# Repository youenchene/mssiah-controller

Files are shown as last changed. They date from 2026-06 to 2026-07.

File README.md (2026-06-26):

# MSSIAH Controller

3D-printable enclosure (case) for a DIY MSSIAH controller for the Commodore 64.
Designed in OpenSCAD — two-piece snap-together case with a 20° sloped face,
parametric dimensions, and integrated heat-set insert pockets.

## What is the MSSIAH controller?

[MSSIAH](https://mssiah.com/mssiah.php) is a cartridge/software suite that turns
the Commodore 64 into a MIDI workstation and synthesizer.

This project reproduces a custom physical controller enclosure inspired by the
build documented at [c64customs](https://c64customs.blogspot.com/2021/08/custom-diy-mssiah-controller.html).
The controller connects to the C64 via the **user port (CB8)** through a DB9
connector, and provides physical knobs, a joystick, and an arcade button to
interact with the MSSIAH software.

## STL models

Pre-built STL files are in the [`stl/`](stl/) directory once exported.

To generate them yourself from the parametric source:

1. Open `main.scad`, `bac.scad`, or `couvercle.scad` in [OpenSCAD](https://openscad.org/)
2. Hit **F6** to render
3. File → Export → Export as STL

| File | Part | Description |
|---|---|---|
| `stl/bac.stl` | Bac (bottom) | Flat base + walls + boss pillars + alignment lip |
| `stl/couvercle.stl` | Couvercle (top) | Sloped face with all control cutouts + DB9 opening |

> The `.scad` source is parametric — adjust dimensions in
> [`lib/dimensions.scad`](lib/dimensions.scad) before exporting to adapt the
> enclosure to different components or tolerances.

## Hardware list

### Electronic components

| Qty | Component | Key specs | Source |
|-----|---|---|---|
| 4× | **Potentiometer** B10K rotary | Shaft Ø 9.7 mm, hex nut 13.85 mm AF, decorative washer Ø 41 mm, knob Ø 26.5 mm | [AliExpress](https://fr.aliexpress.com/item/32847136499.html) |
| 1× | **Joystick** analog (PS2-style) | Cap Ø 15 mm, PCB 34×34 mm, 4 mounting holes Ø 2.5 mm at 35 mm center distance | [AliExpress](https://fr.aliexpress.com/item/1005005367139157.html) |
| 1× | **Arcade button** Sanwa OBSF-30 | Snap-in, head Ø 30 mm, collar Ø 33 mm | [Amazon](https://www.amazon.fr/dp/B01MRWL6DW) |
| 1× | **DB9 connector** female 9-pin | Chassis-mount, body ~30×13 mm, 2 mounting holes | [AliExpress](https://fr.aliexpress.com/item/1005009405056447.html) |

### Fasteners & inserts

| Usage | Insert | Screw | Qty |
|---|---|---|-----|
| Joystick mounting | M2.5 (Ø 3.5 ext, length 4 mm) | M2.5 × 8 mm | 4 |
| DB9 connector | M3 (Ø 5 ext, length 4 mm) | M3 × 8 mm | 2 |
| Case assembly (bac → couvercle) | M3 (Ø 5 ext, length 4 mm) | M3 × 10 mm | 4 |
| Potentiometers | — (hex nut M6 provided) | — | 4 |
| Arcade button | — (snap-in) | — | 1 |
| Feet | — | Adhesive pads Ø 11 mm ([AliExpress](https://fr.aliexpress.com/item/1005006618909639.html)) | 4 |

**Inserts to buy**: 4× M2.5 brass heat-set inserts (Ø 3.5 ext, length 4 mm).
M3 inserts (×6 total) are assumed already in inventory.

### Tools

- Soldering iron (or dedicated insert press) for heat-set inserts
- M2.5 and M3 hex drivers
- OpenSCAD (free, [openscad.org](https://openscad.org/)) to view or modify the model

## Project structure

```
.
├── main.scad          # Full assembly (view: assembled or exploded)
├── bac.scad           # Bottom half — base, walls, bosses, alignment lip
├── couvercle.scad     # Top half — sloped face, control cutouts, DB9 opening
├── lib/
│   ├── dimensions.scad   # All dimensional variables
│   ├── inserts.scad      # Parametric heat-set insert modules
│   ├── composants.scad   # Cutout modules for each component
│   └── passe_cables.scad # Internal cable-routing arches
├── stl/               # Exported STL files
├── PLAN.md            # Full design specification (in French)
├── CONTEXT.md         # Glossary & terminology (in French)
└── LICENSE
```

## Opening in OpenSCAD

Open `main.scad` to see the full assembly. Toggle the flags at the top:

```openscad
EXPLODED = true;        // true = exploded view, false = assembled
SHOW_BAC = true;
SHOW_COUVERCLE = true;
```

Set `EXPLODED = false` for a print-ready view before exporting.

## License

[Unlicense](LICENSE) — public domain. Do whatever you want.

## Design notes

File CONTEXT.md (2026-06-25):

# Glossary — MSSIAH Controller Enclosure

## Parts

- **Bottom** : lower half of the enclosure. Flat base + 4 vertical walls + 4 fixation bosses. Receives the electronics from underneath.
- **Cover** : upper half of the enclosure. Carries the sloped face on which the controls are mounted (joystick, button, potentiometers). Screws onto the bottom.
- **Sloped face** : flat surface at 20° to the horizontal, facing the operator (back high, front low). Carries all controls.
- **Boss** : vertical cylindrical pillar printed inside the bottom, containing a heat-set insert. Serves as a fixation point to screw the cover on.
- **Local reinforcement** : thickened area of the sloped face (or a wall) at a component location, to house an insert or nut and stiffen the fixation.
- **Male lip** : stepped rim on the bottom perimeter, which inserts into the cover groove for self-alignment.
- **Groove** : female channel in the cover rim, which receives the bottom's male lip.
- **Cable guide** : small arch printed in relief on the inner face of the cover, under which cables pass for routing.

## Electronic Components

- **Potentiometer (pot)** : rotary potentiometer B10K. Threaded shaft Ø 9.7 mm, hex nut 13.85 mm across-flats, decorative washer Ø 41 mm, knob Ø 26.5 mm. Body Ø 28 mm, height 12.6 mm under the face.
- **Joystick** : analog module (PS2 type). Cap Ø 15 mm, wider base, PCB 34×34 mm with 4 fixation holes Ø 2.5 mm (M2.5 screws) at 35 mm spacing. Mounted under the sloped face, cap protrudes through Ø 32 mm hole. Fixation via M2.5 heat-set inserts (Ø 3.5 ext, length 4 mm) + M2.5 screws.
- **Arcade button** : Sanwa OBSF-30, snap-in. Head Ø 30 mm, collar Ø 33 mm, depth ~40 mm under the face. Clips into a Ø 30 mm hole, no screws.
- **DB9** : female 9-pin chassis connector. Body ~30×13 mm, fixed by 2 M3 screws on the back face. Connects the controller to the C64's CB8 port.

## Heat-Set Inserts

- Knurled brass inserts, heated and pressed into plastic. Metric internal threading.
- Available inventory : M2 (length 2 and 4), M2.5 (length 4, to purchase), M3 (4/6/8), M4 (4/6/8), M5 (4/6/8), M6, M8 (6/10).
- External diameters : M2=3.2, M3=5, M4=6, M5=7, M6=8, M8=10 mm.

## Fasteners Used in This Project

| Use | Insert | Screw | Plastic Drilling |
|---|---|---|---|
| Joystick (×4) | M2.5, Ø 3.5 ext, length 4 mm | M2.5 × 8 mm | Ø 3.0 mm, depth 5 mm |
| DB9 (×2) | M3, Ø 5 ext, length 4 mm | M3 × 8 mm | Ø 4.0 mm, depth 5 mm |
| Bottom/cover assembly (×4) | M3, Ø 5 ext, length 4 mm | M3 × 10 mm | Ø 4.0 mm, depth 5 mm |
| Potentiometers (×4) | None (M6 embedded hex nut supplied) | M6 nut supplied | 14 mm hex socket |

## Sloped Face Coordinate System

- Origin : bottom-left corner (front-left as seen by operator).
- X axis : width (0 to 120 mm), left → right.
- Y axis : length along the slope (0 to ~170 mm), front → back.
- "Up" of the joystick = toward the back of the enclosure (top of the slope).

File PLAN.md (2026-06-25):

# Plan — MSSIAH Controller Enclosure (OpenSCAD)

## Objective

Reproduce the MSSIAH controller enclosure (https://c64customs.blogspot.com/2021/08/custom-diy-mssiah-controller.html) to control the C64 via the CB8 port (https://mssiah.com/mssiah.php). The enclosure is 3D printed, designed in OpenSCAD, and assembled around the pre-existing electronics.

## Design Decisions

### Enclosure

| Parameter | Value |
|---|---|
| Architecture | 2 halves: bottom (lower) + cover (upper) |
| Split | Horizontal, junction plane at the rim |
| External dimensions | 120 × 160 mm (width × depth) |
| Front height (bottom of slope) | 25 mm |
| Back height (top of slope) | 83 mm (25 + 160·tan 20°) |
| Slope angle | 20°, back high, front low |
| Wall thickness | 2.5 mm |
| Bottom base thickness | 2.5 mm |
| Ventilation | None (passive electronics) |

### Assembly of the Two Halves

| Parameter | Value |
|---|---|
| Mechanism | Male lip on the bottom + female groove in the cover |
| Male lip (bottom) | 2 mm thick, 3 mm high |
| Groove (cover) | 2.2 mm wide, 3.2 mm deep |
| Radial clearance | 0.2 mm |
| Axial clearance | 0.2 mm |
| Groove entry chamfer | 0.5 mm × 45° |
| Fixation | 4 M3 inserts (Ø 5 ext, length 4 mm) in the bottom bosses |
| Assembly screws | M3 × 10 mm (×4) |
| Through-hole in cover rim | Ø 3.2 mm |

### Control Layout (sloped face)

Coordinate system: origin at bottom-left corner (front-left as seen by operator). X = width (0–120), Y = length along the slope (0–~170).

| Control | X (mm) | Y (mm) | Row |
|---|---|---|---|
| Joystick | 30 | 130 | 1 (back) |
| Arcade button | 90 | 130 | 1 (back) |
| Potentiometer P1 | 38.5 | 85 | 2 (middle) |
| Potentiometer P2 | 81.5 | 85 | 2 (middle) |
| Potentiometer P3 | 38.5 | 40 | 3 (front) |
| Potentiometer P4 | 81.5 | 40 | 3 (front) |

```
        0     30      38.5   81.5    90      120
        │     │        │      │       │       │
  170 ──┼─────────────────────────────────────┼── back
        │     │        │      │       │       │
        │  [JOY]      │      │    [BTN]      │  row 1
        │     │        │      │       │       │
   85 ──┼─────┤       [P1]  [P2]     ├───────┼── row 2
        │     │        │      │       │       │
   40 ──┼─────┤       [P3]  [P4]     ├───────┼── row 3
        │     │        │      │       │       │
    0 ──┼─────────────────────────────────────┼── front
```

### Component Mounting

#### Potentiometers (×4)

| Parameter | Value |
|---|---|
| Pass-through hole (shaft Ø 9.7) | Ø 10 mm |
| Local reinforcement | Ø 22 mm, thickness 4 mm |
| Hexagonal socket (embedded nut) | 14 mm across-flats, depth 4 mm |
| Nut | M6 supplied (13.85 mm across-flats) |
| Decorative outer washer | Ø 41 mm |
| Inner washer | Ø 10 int / 15 ext |
| Knob | Ø 26.5 mm, screw-on |
| Body | Ø 28 mm, height 12.6 mm under the face |
| Fixation | Embedded hex nut (anti-rotation) + washer + external nut |

#### Joystick (×1)

| Parameter | Value |
|---|---|
| Pass-through hole (cap + base) | Ø 32 mm |
| Local reinforcement | 45 × 45 mm, thickness 6 mm |
| Insert spacing | 35 × 35 mm |
| Inserts | M2.5, brass, Ø 3.5 ext, length 4 mm (to purchase) |
| Plastic drilling | Ø 3.0 mm, depth 5 mm |
| Screws | M2.5 × 8 mm (×4) |
| Cap | Ø 15 mm |
| PCB | 34 × 34 mm, 4 holes Ø 2.5 mm |

#### Arcade Button Sanwa OBSF-30 (×1)

| Parameter | Value |
|---|---|
| Pass-through hole | Ø 30 mm |
| Face thickness (no reinforcement) | 2.5 mm |
| Fixation | Snap-in (screwless, spring-loaded collar) |
| Collar | Ø 33 mm |
| Depth under the face | ~40 mm |
| Available height at Y=130 | ~64 mm → OK |

#### DB9 (×1)

| Parameter | Value |
|---|---|
| Face | Back (vertical) |
| Position | X=60 mm (centered), Y=20 mm from bottom |
| Cutout | 32 × 15 mm (rectangle) |
| Inserts | M3, brass, Ø 5 ext, length 4 mm (×2) |
| Insert spacing | ~25 mm |
| Plastic drilling | Ø 4.0 mm, depth 5 mm |
| Screws | M3 × 8 mm (×2) |
| Local reinforcement (back face) | 45 × 20 mm, thickness 6 mm |

### Bottom Structure (lower half)

| Parameter | Value |
|---|---|
| Base | 120 × 160 mm, thickness 2.5 mm |
| Walls | 4 vertical walls, thickness 2.5 mm |
| Fixation bosses | 4 pillars Ø 10 mm at corners, M3 inserts |
| Boss position | ~10 mm from edges |
| Foot pads | 4 × Ø 11 mm (adhesive, under the base) |
| Stiffening ribs | 2 diagonals on the base |
| Internal structure | Empty (components are carried by the cover) |

### Cover Structure (upper half)

| Parameter | Value |
|---|---|
| Sloped face | Plane at 20°, 120 × ~170 mm |
| Walls | 4 vertical walls (front 25 mm, back 83 mm, 2 trapezoidal sides) |
| Local reinforcements | At component locations (see above) |
| Cable guides | 3 arches printed on the inner face |
| Peripheral groove | 2.2 × 3.2 mm, chamfer 0.5 × 45° |

### Cable Guides (×3)

Positioned on the inner face of the cover to guide cables toward the DB9 (back):
- Cable guide 1: between row 1 and DB9 (guides joystick + button cables)
- Cable guide 2: between row 2 and row 1 (guides P1/P2 cables)
- Cable guide 3: between row 3 and row 2 (guides P3/P4 cables)

Arches ~5 mm high, cables pass underneath.

## Fasteners Inventory

| Use | Insert | Screw | Quantity |
|---|---|---|---|
| Joystick | M2.5, Ø 3.5 ext, length 4 mm | M2.5 × 8 mm | 4 |
| DB9 | M3, Ø 5 ext, length 4 mm | M3 × 8 mm | 2 |
| Bottom/cover assembly | M3, Ø 5 ext, length 4 mm | M3 × 10 mm | 4 |
| Potentiometers | None (M6 nut supplied) | M6 nut supplied | 4 |
| Arcade button | None (snap-in) | — | — |
| Foot pads | None | Adhesive | 4 |

**Total inserts to purchase**: 4 × M2.5 (Ø 4 ext, length 4 mm)
**Total screws**: 4 × M2.5×8, 2 × M3×8, 4 × M3×10

## OpenSCAD Project Structure

```
mssiah-controller/
├── CONTEXT.md              # Glossary (project terminology)
├── PLAN.md                 # This file
├── main.scad               # Full assembly (3D view)
├── bottom.scad             # Lower half (bottom)
├── cover.scad              # Upper half (cover + sloped face)
├── lib/
│   ├── dimensions.scad    # All dimensional variables
│   ├── inserts.scad        # Heat-set insert modules (models)
│   ├── components.scad    # Drill/cutout modules for each component
│   └── cable_guides.scad   # Cable guide modules
└── stl/                    # Exported STL files (generated)
    ├── bottom.stl
    └── cover.stl
```

## Build Order

1. **`lib/dimensions.scad`** : All variables (dimensions, positions, angles)
2. **`lib/inserts.scad`** : Parametric insert modules (drill hole + socket)
3. **`lib/components.scad`** : Cutout modules for each component (pot, joystick, button, DB9)
4. **`lib/cable_guides.scad`** : Cable guide arch module
5. **`cover.scad`** : Assembly of sloped face + walls + reinforcements + cutouts + cable guides + groove
6. **`bottom.scad`** : Assembly of base + walls + bosses + ribs + lip + feet
7. **`main.scad`** : Assembly of both halves (exploded + closed 3D view)
8. **STL export** : `bottom.stl` and `cover.stl`

## Reference Views

### Side Profile (from the right)

```
        back                      front
       83mm                      25mm

   83mm ┌─╲
        │   ╲
        │     ╲
        │       ╲
        │         ╲
        │           ╲
        │             ╲
        │               ╲
        │                 ╲
        │                   ╲
        │                     ╲
        │                       ╲
        │                         ╲
        │                           ╲
   25mm │                             └──┐
        └──────────────────────────────────┘
        ←──────────── 160 mm ──────────────→
```

### Sloped Plane View (control layout)

```
        ←──────── 120 mm ────────→
   ┌──────────────────────────────────┐
   │                                  │  ← back (top of slope)
   │   [JOY]                  [BTN]   │   row 1
   │                                  │
   │          [P1]      [P2]         │   row 2
   │                                  │
   │          [P3]      [P4]          │   row 3
   │                                  │  ← front (bottom of slope)
   └──────────────────────────────────┘
   ←────────── ~170 mm ──────────────→
```

### Back View (DB9)

```
        ←──────── 120 mm ────────→
   83mm ┌──────────────────────────┐
        │                          │
        │                          │
        │                          │
        │      ┌────────┐          │
   20mm │      │  DB9   │          │
        │      └────────┘          │
        │  ◯               ◯       │  ← M3 inserts
        └──────────────────────────┘
```

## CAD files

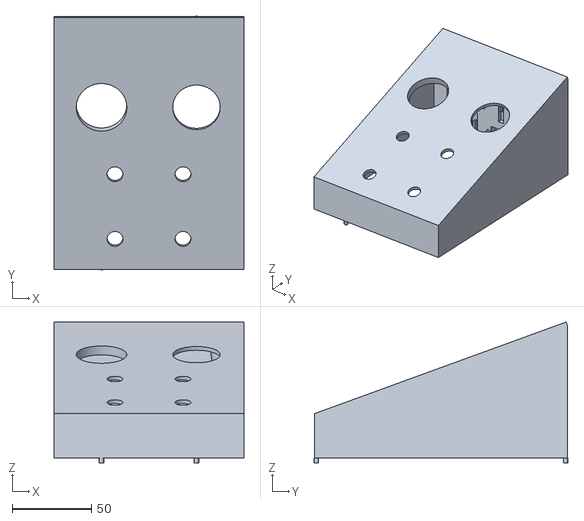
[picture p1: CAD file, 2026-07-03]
stl/cover.stl
120.0 x 160.5 x 89.1

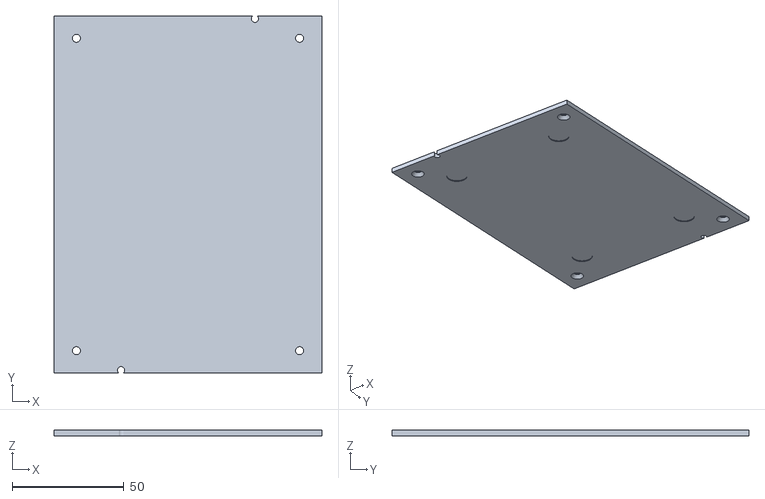
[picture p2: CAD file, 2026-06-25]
stl/bottom.stl
120.0 x 160.0 x 2.50

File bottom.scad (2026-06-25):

// =============================================================================
// bottom.scad — Flat base plate
// =============================================================================
// Plate 120×160×2.5 mm. The cover handles everything else.

include <lib/dimensions.scad>

t = WALL_THICKNESS;

// -----------------------------------------------------------------------------
// Foot pad recesses (cutout under the base)
// -----------------------------------------------------------------------------
module bottom_foot_recesses() {
    m = FOOT_EDGE_MARGIN;
    positions = [
        [m, m], [WIDTH - m, m],
        [m, DEPTH - m], [WIDTH - m, DEPTH - m],
    ];
    for (pos = positions) {
        translate([pos[0], pos[1], -0.1])
            cylinder(d = FOOT_DIAMETER, h = FOOT_RECESS_DEPTH + 0.1);
    }
}

// -----------------------------------------------------------------------------
// Through-holes + countersink for M3 assembly screws
// -----------------------------------------------------------------------------
module bottom_assembly_screw_holes() {
    m = BOSS_EDGE_MARGIN;
    positions = [
        [m, m], [WIDTH - m, m],
        [m, DEPTH - m], [WIDTH - m, DEPTH - m],
    ];
    for (pos = positions) {
        // Through-hole for M3 screw
        translate([pos[0], pos[1], -0.1])
            cylinder(d = 3.6, h = BASE_THICKNESS + 0.2);
        // Conical countersink for flat-head screw (bottom side)
        translate([pos[0], pos[1], -0.1])
            cylinder(d1 = 7, d2 = 3.6, h = 2);
    }
}

// -----------------------------------------------------------------------------
// Alignment holes for cover pins
// -----------------------------------------------------------------------------
module bottom_alignment_holes() {
    d = 3.2;  // hole diameter (0.2 mm clearance on Ø 3 pin)

    // Front (wall center)
    translate([30, t/2, -0.1])
        cylinder(d = d, h = BASE_THICKNESS + 0.2);
    // Back (wall center)
    translate([WIDTH - 30, DEPTH - t/2, -0.1])
        cylinder(d = d, h = BASE_THICKNESS + 0.2);
}

// -----------------------------------------------------------------------------
// Complete bottom (flat plate)
// -----------------------------------------------------------------------------
module bottom() {
    difference() {
        cube([WIDTH, DEPTH, BASE_THICKNESS]);
        bottom_foot_recesses();
        bottom_assembly_screw_holes();
        bottom_alignment_holes();
    }
}

bottom();

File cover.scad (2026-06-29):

// =============================================================================
// cover.scad — Main body with sloped face and full-height walls
// =============================================================================
// FIX:
// 1. Bosses connected to the sloped plane via vertical reinforcements
// 2. Sloped plane cut straight at the front (y=0)
// 3. Side wall: inner point corrected (h_back instead of h_back - t)

include <lib/dimensions.scad>
use <lib/components.scad>

t = WALL_THICKNESS;
h_front = COVER_HEIGHT_FRONT;   // 3 mm
h_back  = COVER_HEIGHT_BACK;    // ≈ 61 mm

// Height of the sloped plane at a given Y position (world frame)
function z_slope(y) = h_front + y * tan(SLOPE_ANGLE);

// -----------------------------------------------------------------------------
// Flat sloped face (in XY plane, before rotation)
// z = 0 → inner face, z = t → outer face
// -----------------------------------------------------------------------------
module sloped_face_flat() {
    difference() {
        union() {
            cube([WIDTH, SLOPE_LENGTH, t]);

            // Joystick reinforcement (inner side)
            translate([JOY_POSITION[0], JOY_POSITION[1], -(JOY_REINFORCE_THICKNESS - t)])
                translate([-JOY_REINFORCE_SIZE/2, -JOY_REINFORCE_SIZE/2, 0])
                    cube([JOY_REINFORCE_SIZE, JOY_REINFORCE_SIZE,
                          JOY_REINFORCE_THICKNESS - t]);
        }

        // Pots — through-holes (flat face)
        for (pos = POT_POSITIONS) {
            translate([pos[0], pos[1], -10])
                cylinder(d = POT_HOLE_DIAMETER, h = 100);
        }

        // Anti-rotation tab slots — 2 per pot (left/right)
        sw  = POT_TAB_WIDTH  + POT_TAB_CLEARANCE;   // 1.2 mm
        sl  = POT_TAB_LENGTH + POT_TAB_CLEARANCE;   // 3.1 mm
        sd  = min(POT_TAB_DEPTH + POT_TAB_CLEARANCE,
                  WALL_THICKNESS - POT_TAB_SLOT_FLOOR);  // capped at 1.5 mm
        hs  = POT_TAB_SPAN  / 2;                    // 12.4 mm
        for (pos = POT_POSITIONS) {
            translate([pos[0], pos[1], 0]) {
                // Left tab
                translate([-hs - sw/2, -sl/2, -0.1])
                    cube([sw, sl, sd + 0.1]);
                // Right tab
                translate([+hs - sw/2, -sl/2, -0.1])
                    cube([sw, sl, sd + 0.1]);
            }
        }

        // Joystick — through-hole
        translate([JOY_POSITION[0], JOY_POSITION[1], -10])
            cylinder(d = JOY_HOLE_DIAMETER, h = 100);
        // 4 M2.5 insert holes (inner side)
        for (dx = [-JOY_PCB_SPACING/2, JOY_PCB_SPACING/2],
             dy = [-JOY_PCB_SPACING/2, JOY_PCB_SPACING/2]) {
            translate([JOY_POSITION[0] + dx, JOY_POSITION[1] + dy,
                       -(JOY_REINFORCE_THICKNESS - t) - 0.1])
                cylinder(d = insert_dims(INSERT_JOYSTICK_M)[2],
                         h = insert_dims(INSERT_JOYSTICK_M)[3] + 0.1);
        }

        // Arcade button — through-hole
        translate([BTN_POSITION[0], BTN_POSITION[1], -10])
            cylinder(d = BTN_HOLE_DIAMETER, h = 100);
    }
}

// -----------------------------------------------------------------------------
// FIX 2: Sloped plane positioned + clipped at y=0 (front)
// -----------------------------------------------------------------------------
module cover_sloped_face() {
    intersection() {
        // Rotated sloped plane
        translate([0, 0, h_front])
            rotate([SLOPE_ANGLE, 0, 0])
                sloped_face_flat();
        // Clip at y >= 0 (cuts front overhang)
        translate([-10, 0, -10])
            cube([WIDTH + 20, DEPTH + 20, h_back + 20]);
    }
}

// -----------------------------------------------------------------------------
// Cable guides — 3 arches on the sloped face (offset toward joystick side)
// -----------------------------------------------------------------------------
module cable_guide_flat() {
    difference() {
        translate([-CABLE_GUIDE_WIDTH/2, -CABLE_GUIDE_WIDTH/2, -CABLE_GUIDE_HEIGHT])
            cube([CABLE_GUIDE_WIDTH, CABLE_GUIDE_WIDTH, CABLE_GUIDE_HEIGHT]);
        translate([-CABLE_GUIDE_WIDTH/2 + CABLE_GUIDE_THICKNESS,
                   -CABLE_GUIDE_WIDTH/2 - 0.1, -CABLE_GUIDE_HEIGHT])
            cube([CABLE_GUIDE_WIDTH - 2*CABLE_GUIDE_THICKNESS,
                  CABLE_GUIDE_WIDTH + 0.2,
                  CABLE_GUIDE_HEIGHT - CABLE_GUIDE_THICKNESS]);
    }
}

module cover_face_cable_guides() {
    // Only the 2 guides closest to the top
    for (y = [CABLE_GUIDE_POSITIONS_Y[0], CABLE_GUIDE_POSITIONS_Y[1]]) {
        translate([0, 0, h_front])
            rotate([SLOPE_ANGLE, 0, 0])
                translate([WIDTH/2, y, 0])
                    cable_guide_flat();
    }
}

// -----------------------------------------------------------------------------
// Cable guides — 2 arches oriented forward on each side of a DB9
// cx, cz : position on the back face
// -----------------------------------------------------------------------------
module cover_db9_cable_guides(cx, cz) {
    y_wall = DEPTH;  // outer face

    offsets = [30, -30];

    for (dx = offsets) {
        translate([cx + dx, y_wall, cz])
            rotate([-90, 0, 0])
                cable_guide_flat();
    }
}

// -----------------------------------------------------------------------------
// Bosses with enlarged reinforcement cones trimmed flush to the sloped face
// -----------------------------------------------------------------------------
module cover_bosses() {
    m = BOSS_EDGE_MARGIN;
    boss_height = BASE_HEIGHT - BASE_THICKNESS;  // 22.5 mm
    insert_d = insert_dims(INSERT_ASSEMBLY_M)[2];
    insert_h = insert_dims(INSERT_ASSEMBLY_M)[3];
    cone_top_d = BOSS_DIAMETER + 16;  // 26 mm, enlarged for structural connection

    positions = [
        [m, m], [WIDTH - m, m],
        [m, DEPTH - m], [WIDTH - m, DEPTH - m],
    ];

    // Outer difference: trim everything above the sloped face inner surface
    difference() {
        // All bosses with oversized cones (extend past inner face for overlap)
        for (pos = positions) {
            z_top = z_slope(pos[1]);   // inner face height at this Y
            jy = JOY_POSITION[1] * cos(SLOPE_ANGLE);

            difference() {
                union() {
                    // Pillar extending down into the base
                    translate([pos[0], pos[1], -boss_height])
                        cylinder(d = BOSS_DIAMETER, h = boss_height + t);

                    // Enlarged reinforcement cone (except boss near joystick)
                    if (pos[0] != m || pos[1] != DEPTH - m) {
                        translate([pos[0], pos[1], 0])
                            cylinder(d1 = BOSS_DIAMETER,
                                     d2 = cone_top_d,
                                     h  = z_top + 2);
                    }
                }

                // Insert hole at the BOTTOM of the boss (base side)
                translate([pos[0], pos[1], -boss_height - 0.1])
                    cylinder(d = insert_d, h = insert_h + 0.1);

                // Clear the joystick mounting area
                if (pos[0] == m && pos[1] == DEPTH - m) {
                    translate([JOY_POSITION[0] - JOY_REINFORCE_SIZE/2 - 5,
                               jy - JOY_REINFORCE_SIZE/2 - 5,
                               -1])
                        cube([JOY_REINFORCE_SIZE + 10,
                              JOY_REINFORCE_SIZE + 10,
                              h_back + 2]);
                }
            }
        }

        // Trim 1 : cut off anything above the sloped face inner surface.
        // Inner surface is at z=0 in the flat (rotated) coordinate frame.
        translate([-1, -1, h_front])
            rotate([SLOPE_ANGLE, 0, 0])
                translate([0, 0, 0])
                    cube([WIDTH + 2, SLOPE_LENGTH + 2, 200]);

        // Trim 2 : cut off cone overhang beyond the outer face of each wall.
        // Left wall  (x < 0)
        translate([-100, -1, -boss_height - 1])
            cube([100, DEPTH + 2, h_back + boss_height + 5]);
        // Front wall (y < 0)
        translate([-1, -100, -boss_height - 1])
            cube([WIDTH + 2, 100, h_back + boss_height + 5]);
        // Right wall (x > WIDTH)
        translate([WIDTH, -1, -boss_height - 1])
            cube([100, DEPTH + 2, h_back + boss_height + 5]);
        // Back wall  (y > DEPTH)
        translate([-1, DEPTH, -boss_height - 1])
            cube([WIDTH + 2, 100, h_back + boss_height + 5]);
    }
}

// -----------------------------------------------------------------------------
// Base plate (rim) + connection pegs to bosses
// -----------------------------------------------------------------------------
module cover_rim() {
    difference() {
        cube([WIDTH, DEPTH, t]);
        translate([t, t, -0.1])
            cube([WIDTH - 2*t, DEPTH - 2*t, t + 0.2]);
    }
}
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

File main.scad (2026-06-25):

// =============================================================================
// main.scad — Full assembly (3D view of both halves)
// =============================================================================
// Shows the bottom and cover assembled or in exploded view.

include <lib/dimensions.scad>
use <bottom.scad>
use <cover.scad>

// -----------------------------------------------------------------------------
// Display parameters
// -----------------------------------------------------------------------------
EXPLODED = true;       // true = exploded view, false = assembled
SHOW_BOTTOM = true;
SHOW_COVER = true;

// Vertical offset for exploded view
explode_offset = EXPLODED ? 40 : 0;

// -----------------------------------------------------------------------------
// Assembly
// -----------------------------------------------------------------------------
module assembly() {
    if (SHOW_BOTTOM) {
        color("lightgray", 0.9)
            bottom();
    }

    if (SHOW_COVER) {
        color("lightblue", 0.9)
            translate([0, 0, BASE_THICKNESS + explode_offset])
                cover();
    }
}

assembly();

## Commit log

2026-06-25 🐛 fix: orient pot hex nut pockets interior-side, move DB9 to couvercle
    [bac.scad, couvercle.scad, main.scad]
2026-06-25 🔥 fix: remove pot renforts and hex pockets, lower DB9 to 15mm
    [couvercle.scad]
2026-06-25 🐛 fix: add screw countersink, shallow patin guides, offset patins from screws
    [bac.scad]
2026-06-25 🦺 feat: add boss cone reinforcement, corner block, fix bac ribs
    [bac.scad, couvercle.scad]
2026-06-25 🔥 fix: remove cone from boss near joystick
    [couvercle.scad]
2026-06-25 🏗️ refactor: flat bac plate, couvercle full-height walls, alignment pegs
    [bac.scad, couvercle.scad, main.scad]
2026-06-25 🐛 fix: corner block height to boss level, prevent sloped face protrusion
    [couvercle.scad]
2026-06-25 ✨ feat: add cable guides on sloped face (x2) and DB9 sides (x2)
    [couvercle.scad]
2026-06-25 🍱 assets: add updated STL export of bac and couvercle (+gitignore)
    [bac.stl, couvercle.stl]
2026-06-25 🌐 feat: translate project from French to English
    [bac.scad, bottom.scad, bottom.stl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]
2026-06-26 📝 docs: add README with project overview, hardware BOM, and purchase links
2026-06-29 ✨ feat: add anti-rotation tab slots and reposition components
    [cover.scad]
2026-06-29 🐛 fix: enlarge boss cones and trim to connect sloped face and prevent wall overhang
    [cover.scad]
2026-06-29 🐛 fix: correct DB9 connector dimensions (cutout 19.20mm, screw spacing 24.5mm)
2026-06-29 ♻️ refactor: make DB9 connector a positionable component (3 instances)
    [cover.scad]
2026-06-29 🍱 assets: update cover STL with 3 DB9 connectors
    [cover.stl]
2026-07-03 🐛 fix: adjust insert clearances and front pot positions
    [cover.stl]
